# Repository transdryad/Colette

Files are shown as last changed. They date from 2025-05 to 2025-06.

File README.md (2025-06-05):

# Colette

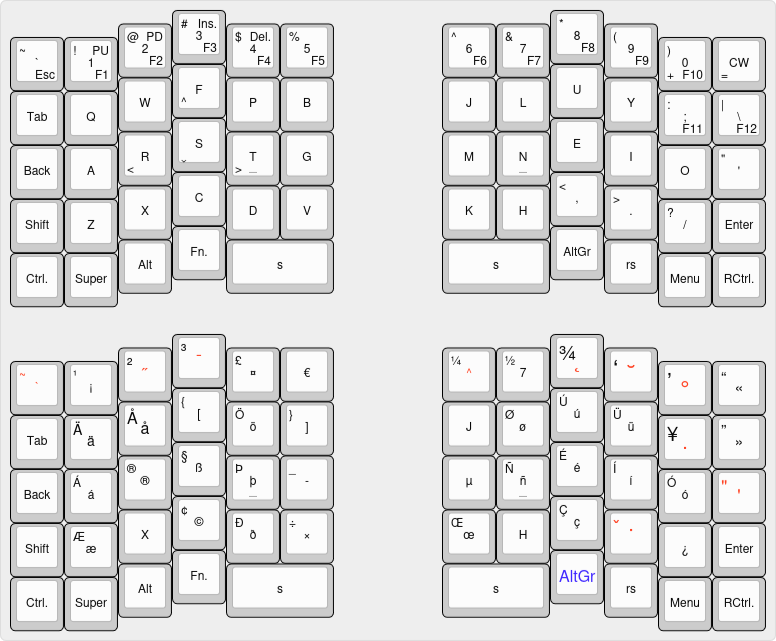
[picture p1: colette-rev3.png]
Colette

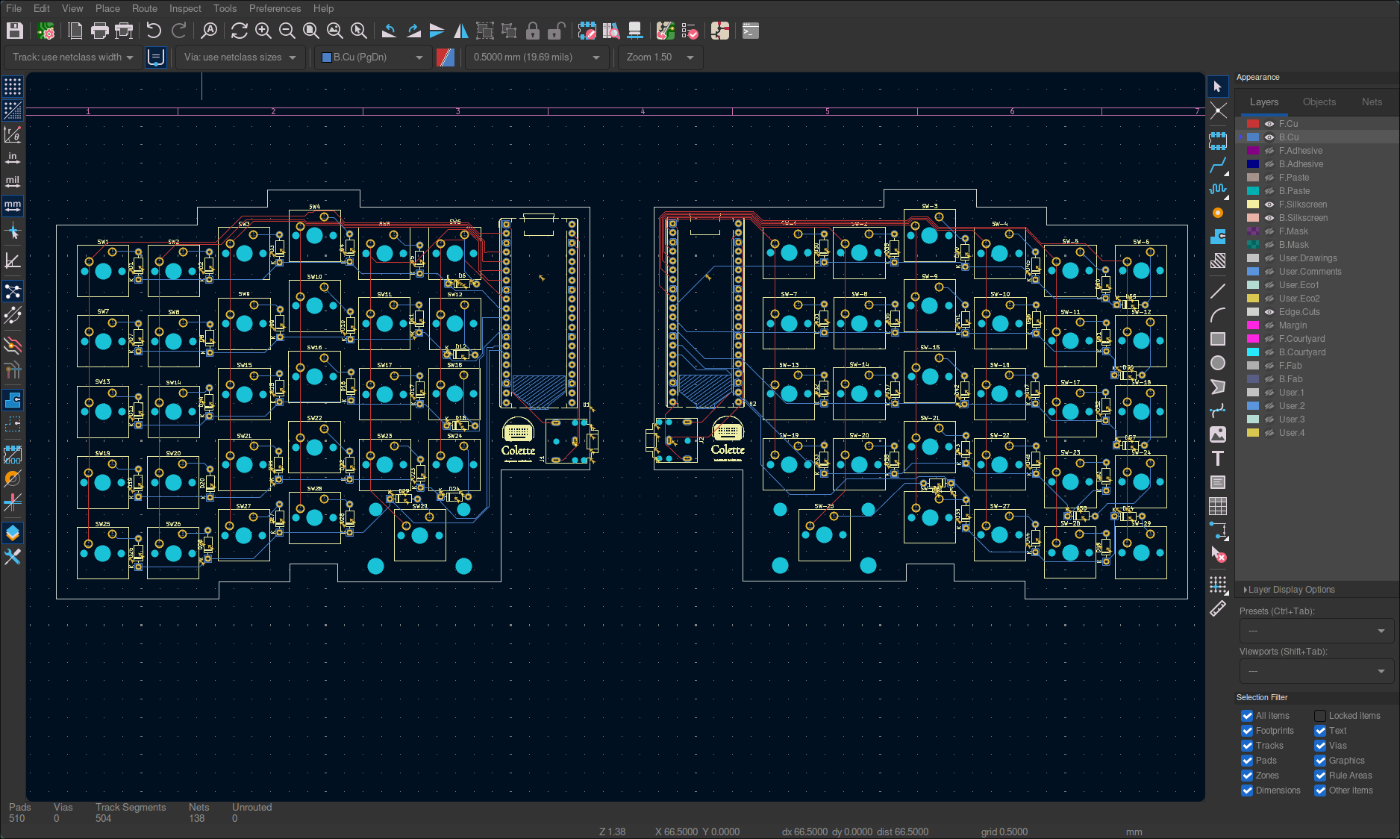
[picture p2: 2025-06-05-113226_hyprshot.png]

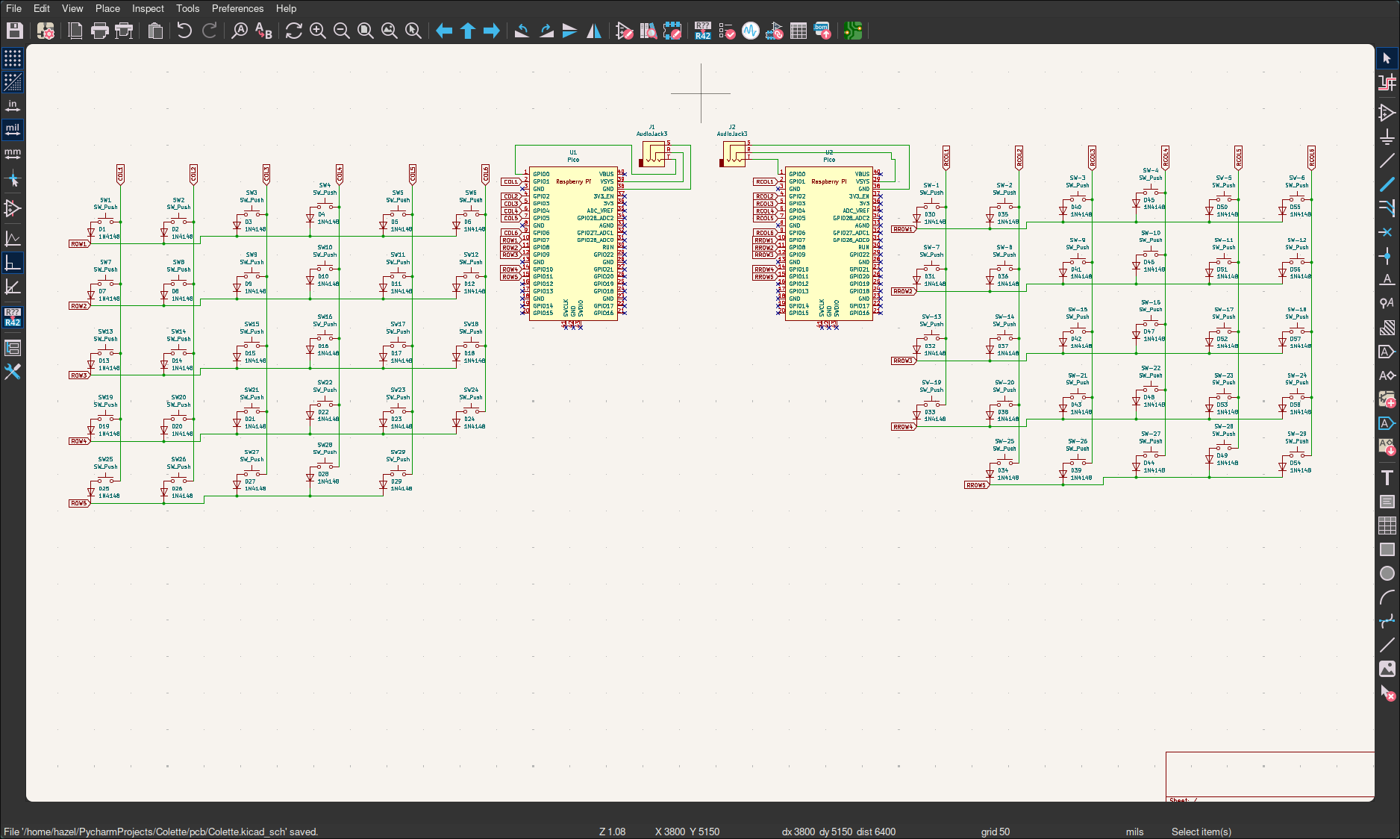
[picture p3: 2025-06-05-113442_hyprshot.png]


A keyboard designed to be ergonomic, clean, convenient, maintainable, and versatile.
It is optimized for English, but can type every character supported by the US International layout (though it's not followed or fully required for basic usage.)
By default, it uses Colemak Mod-DH with a few changes to punctuation.

I made this keyboard to get more experience building hardware and enable a more cohesive coding environment.
I also wanted it to be good at typing text as well and have support for similar languages to english like French,
Spanish, and German.

* Keyboard Maintainer: [Hazel Viswanath](https://github.com/transdryad)
* Hardware Supported: Colette PCB, RPi/Orpheus Pico v1, Cherry MX keys, standard TRS jack

# Software used:
Kicad, Pycharm, FreeCAD, QMK, and Keyboard-Layout-Editor.com

# Firmware:
To compile & flash formware, install qmk system-wide and run bf.sh.
When it's "waiting for drive," plug in while pressing the BOOTSEL button on the PICO.
WARNING: the script will delete qmk firmware monorepo tree.
Backup any changes.

# BOM

BOM also in BOM.csv

| Part | Quantity | Proposed Sourcing? |
|:---|:---|:---|
| PCBs | 2 | https://jlcpcb.com |
| KeySwitches | 58 | https://mechanicalkeyboards.com/products/cherry-mx2a-brown-55g-tactile?variant=48020838351148 |
| Keycaps | ~58 | https://www.amazon.com/YMDK-Profile-Keyset-Mechanical-Keyboard/dp/B07S18VCDN?th=1 |
| 1N4148 Diodes | 58 | https://www.digikey.com/en/products/detail/onsemi/1N4148/458603 |
| TRS Jacks | 2 | https://www.digikey.com/en/products/detail/same-sky-formerly-cui-devices/SJ1-3523N/738689 |
| TRS Cables | 1 | https://www.mycablemart.com/store/cart.php?m=product_detail&p=9040 |
| Orpheus Picos | 2 | HQ? |
| M3x16mm Screws | 8 | ? |
| M3x5mx4mm headset inserts | 8 | ? |
| Case | 4 parts  | Printing legion? |

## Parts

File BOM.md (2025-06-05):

PCBs (2): https://jlcpcb.com
Switches (58): https://mechanicalkeyboards.com/products/cherry-mx2a-brown-55g-tactile?variant=48020838351148
Keycaps (58): https://www.amazon.com/YMDK-Profile-Keyset-Mechanical-Keyboard/dp/B07S18VCDN?th=1 (picked as it contains all sizes that I need w/ exactly the right amount of 1Us.)
Diodes (58): https://www.digikey.com/en/products/detail/onsemi/1N4148/458603
TRS Jacks (2): https://www.digikey.com/en/products/detail/same-sky-formerly-cui-devices/SJ1-3523N/738689
1.5 ft. TRS Cable (1): https://www.mycablemart.com/store/cart.php?m=product_detail&p=9040
Orpheus Picos (2): Hack Club?
M3x16mm Screws (8): ?
M3x5mx4mm headset inserts (8): ?
Case(s) (4 parts): printing legion?

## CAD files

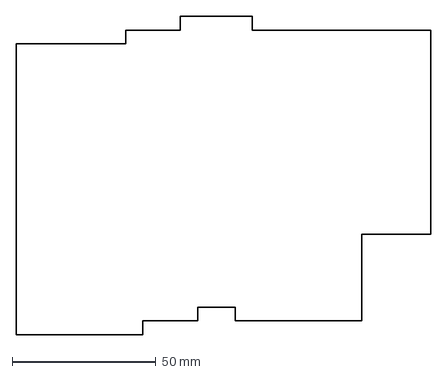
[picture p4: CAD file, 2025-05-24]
CAD/FCSrc/main-BodySketch.dxf
144.3 x 110.8 mm

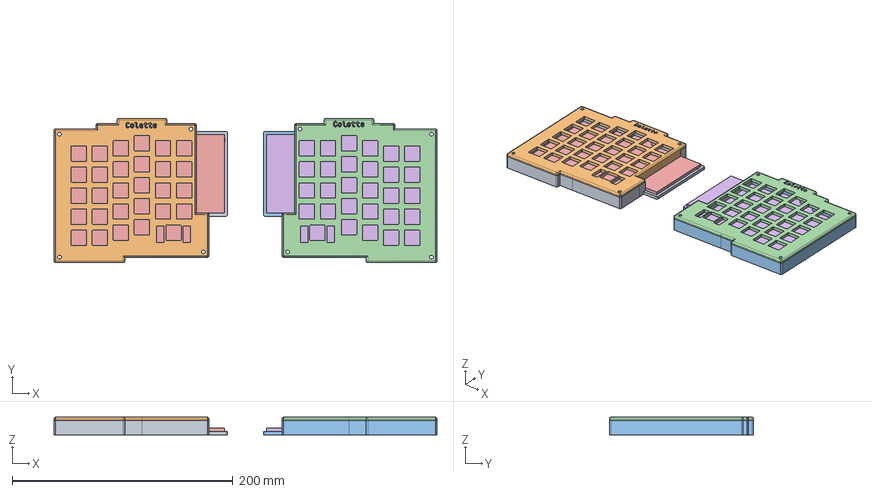
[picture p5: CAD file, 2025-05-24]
CAD/FCSrc/main.FCStd
346.9 x 130.8 x 16.0 mm
Plate

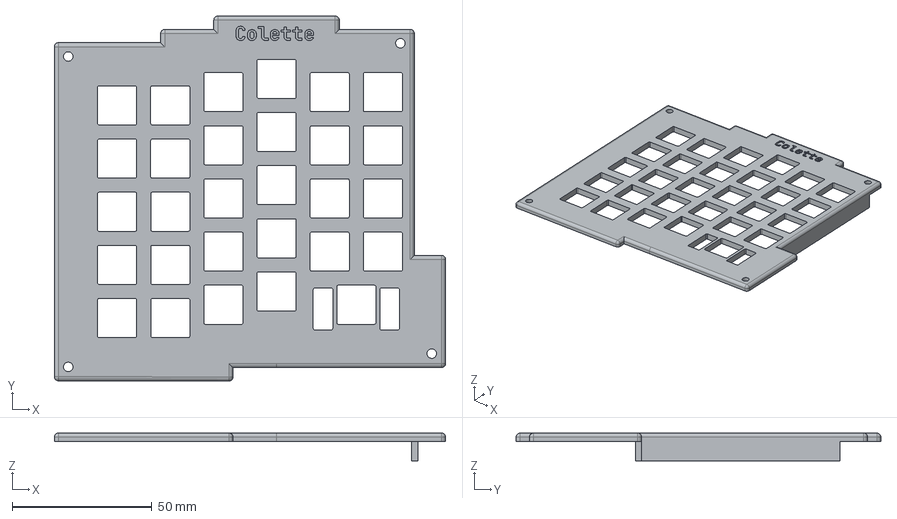
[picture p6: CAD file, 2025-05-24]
production/CAD/plate-left.step
140.3 x 130.8 x 10.0 mm

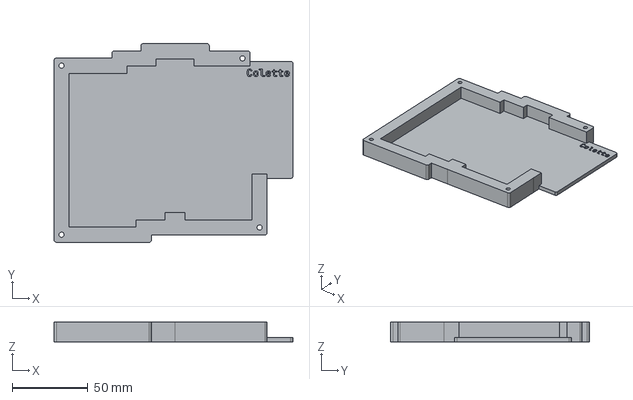
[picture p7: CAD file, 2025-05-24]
production/CAD/case-left.step
157.3 x 130.8 x 13.0 mm

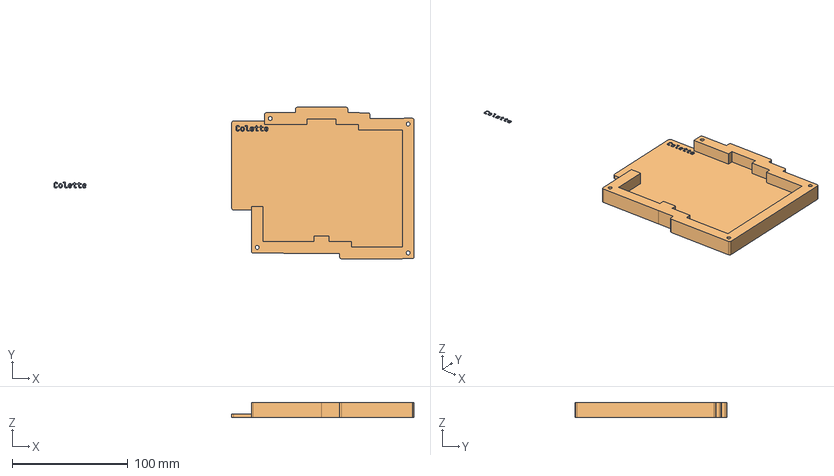
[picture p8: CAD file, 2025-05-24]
production/CAD/case-right.step
310.7 x 130.8 x 13.0 mm
ShapeString002

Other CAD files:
CAD/FCSrc/main-er.FCStd
CAD/all-with-mock-pcb.step
production/CAD/plate-right.step

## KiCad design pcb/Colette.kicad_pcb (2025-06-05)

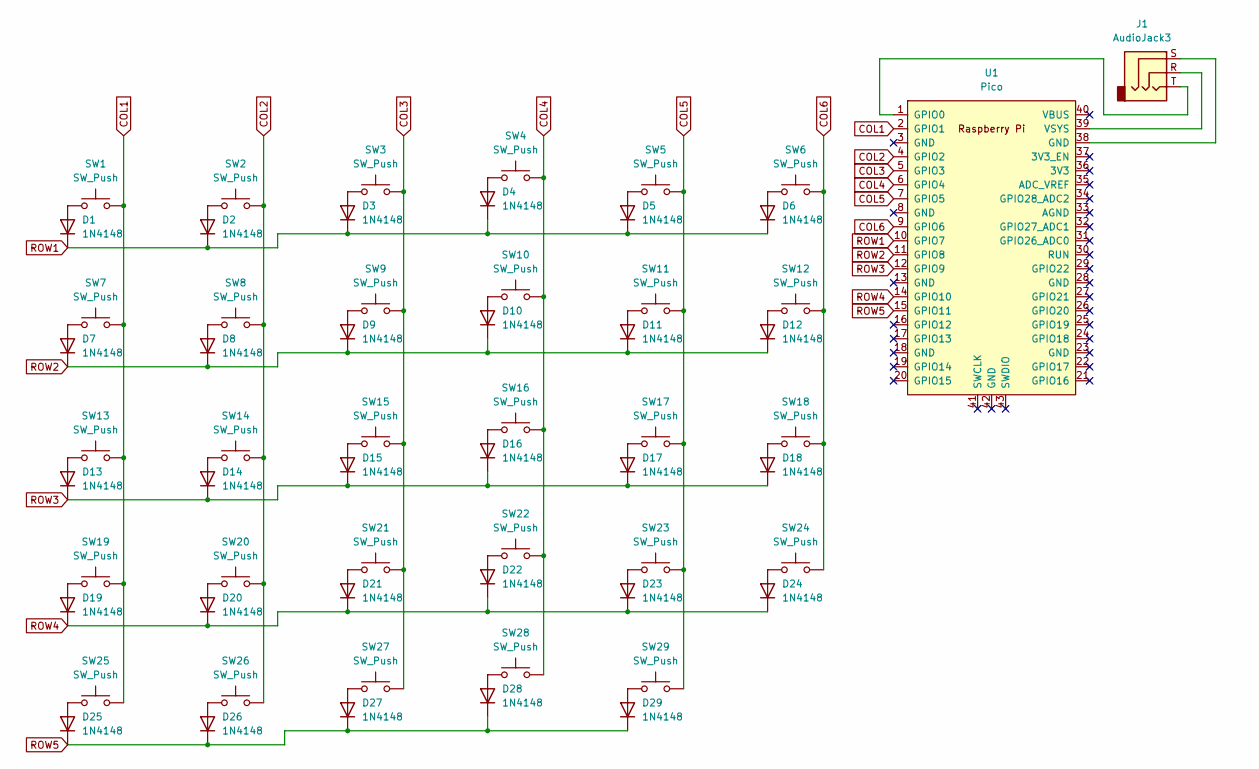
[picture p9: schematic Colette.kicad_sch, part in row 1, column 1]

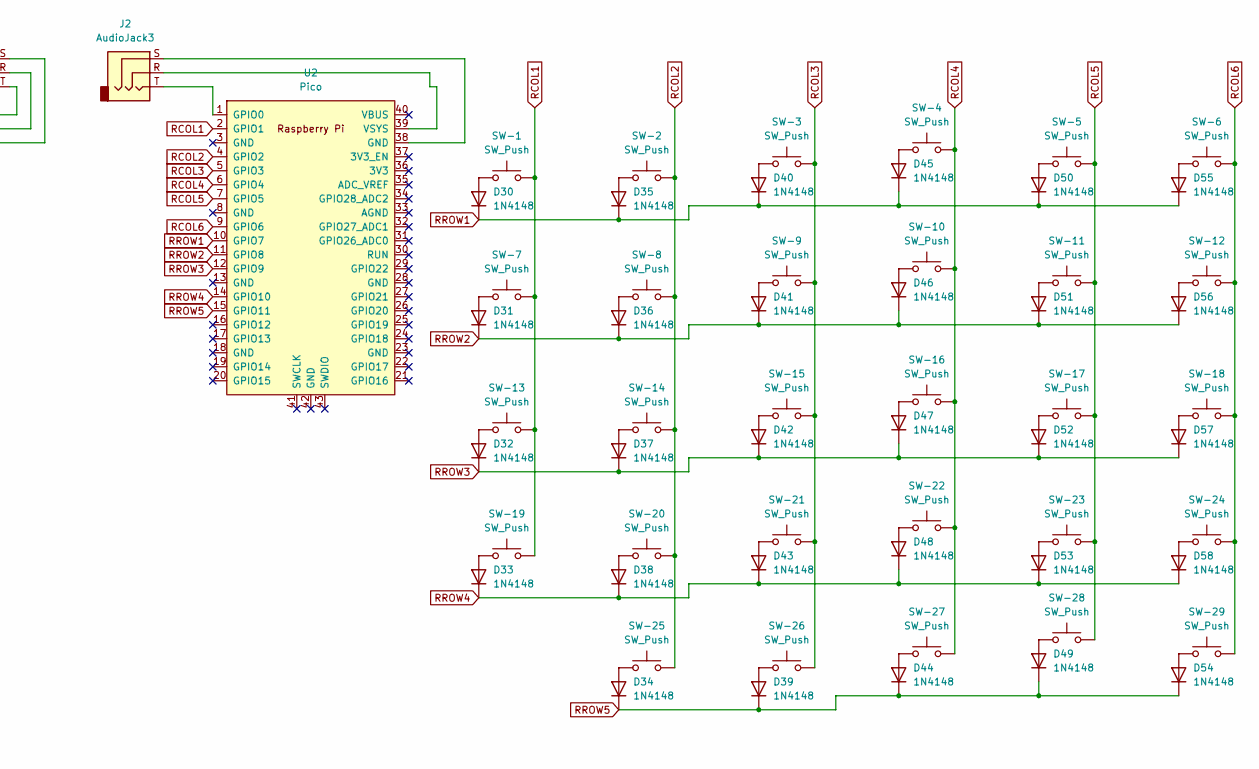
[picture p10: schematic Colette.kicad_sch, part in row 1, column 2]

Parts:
D1, D2, D3, D4, D5, D6, D7, D8, D9, D10, D11, D12, D13, D14, D15, D16, D17, D18, D19, D20, D21, D22, D23, D24, D25, D26, D27, D28, D29, D30, D31, D32, D33, D34, D35, D36, D37, D38, D39, D40, D41, D42, D43, D44, D45, D46, D47, D48, D49, D50, D51, D52, D53, D54, D55, D56, D57, D58: 1N4148; D_DO-35_SOD27_P7.62mm_Horizontal
J1, J2: AudioJack3; Jack_3.5mm_CUI_SJ1-3523N_Horizontal
SW1, SW2, SW3, SW4, SW5, SW6, SW7, SW8, SW9, SW10, SW11, SW12, SW13, SW14, SW15, SW16, SW17, SW18, SW19, SW20, SW21, SW22, SW23, SW24, SW25, SW26, SW27, SW28: SW_Push; SW_Cherry_MX_1.00u_PCB
SW29: SW_Push; SW_Cherry_MX_2.00u_PCB
SW-1, SW-2, SW-3, SW-4, SW-5, SW-6, SW-7, SW-8, SW-9, SW-10, SW-11, SW-12, SW-13, SW-14, SW-15, SW-16, SW-17, SW-18, SW-19, SW-20, SW-21, SW-22, SW-23, SW-24, SW-26, SW-27, SW-28, SW-29: SW_Push; SW_Cherry_MX_1.00u_PCB
SW-25: SW_Push; SW_Cherry_MX_2.00u_PCB
U1, U2: Pico; RaspberryPi_Pico_Common_THT

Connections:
COL1: SW1.2, SW7.2, SW13.2, SW19.2, SW25.2, U1.2 (GPIO1)
COL2: SW2.2, SW8.2, SW14.2, SW20.2, SW26.2, U1.4 (GPIO2)
COL3: SW3.2, SW9.2, SW15.2, SW21.2, SW27.2, U1.5 (GPIO3)
COL4: SW4.2, SW10.2, SW16.2, SW22.2, SW28.2, U1.6 (GPIO4)
COL5: SW5.2, SW11.2, SW17.2, SW23.2, SW29.2, U1.7 (GPIO5)
COL6: SW6.2, SW12.2, SW18.2, SW24.2, U1.9 (GPIO6)
unnamed: D1.2 (A), SW1.1
unnamed: D2.2 (A), SW2.1
unnamed: D3.2 (A), SW3.1
unnamed: D4.2 (A), SW4.1
unnamed: D5.2 (A), SW5.1
unnamed: D6.2 (A), SW6.1
unnamed: D7.2 (A), SW7.1
unnamed: D8.2 (A), SW8.1
unnamed: D9.2 (A), SW9.1
unnamed: D10.2 (A), SW10.1
unnamed: D11.2 (A), SW11.1
unnamed: D12.2 (A), SW12.1
unnamed: D13.2 (A), SW13.1
unnamed: D14.2 (A), SW14.1
unnamed: D15.2 (A), SW15.1
unnamed: D16.2 (A), SW16.1
unnamed: D17.2 (A), SW17.1
unnamed: D18.2 (A), SW18.1
unnamed: D19.2 (A), SW19.1
unnamed: D20.2 (A), SW20.1
unnamed: D21.2 (A), SW21.1
unnamed: D22.2 (A), SW22.1
unnamed: D23.2 (A), SW23.1
unnamed: D24.2 (A), SW24.1
unnamed: D25.2 (A), SW25.1
unnamed: D26.2 (A), SW26.1
unnamed: D27.2 (A), SW27.1
unnamed: D28.2 (A), SW28.1
unnamed: D29.2 (A), SW29.1
unnamed: D30.2 (A), SW-1.1
unnamed: D31.2 (A), SW-7.1
unnamed: D32.2 (A), SW-13.1
unnamed: D33.2 (A), SW-19.1
unnamed: D34.2 (A), SW-25.1
unnamed: D35.2 (A), SW-2.1
unnamed: D36.2 (A), SW-8.1
unnamed: D37.2 (A), SW-14.1
unnamed: D38.2 (A), SW-20.1
unnamed: D39.2 (A), SW-26.1
unnamed: D40.2 (A), SW-3.1
unnamed: D41.2 (A), SW-9.1
unnamed: D42.2 (A), SW-15.1
unnamed: D43.2 (A), SW-21.1
unnamed: D44.2 (A), SW-27.1
unnamed: D45.2 (A), SW-4.1
unnamed: D46.2 (A), SW-10.1
unnamed: D47.2 (A), SW-16.1
unnamed: D48.2 (A), SW-22.1
unnamed: D49.2 (A), SW-28.1
unnamed: D50.2 (A), SW-5.1
unnamed: D51.2 (A), SW-11.1
unnamed: D52.2 (A), SW-17.1
unnamed: D53.2 (A), SW-23.1
unnamed: D54.2 (A), SW-29.1
unnamed: D55.2 (A), SW-6.1
unnamed: D56.2 (A), SW-12.1
unnamed: D57.2 (A), SW-18.1
unnamed: D58.2 (A), SW-24.1
unnamed: J1.S, U1.38 (GND)
unnamed: J2.S, U2.38 (GND)
unnamed: J1.T, U1.1 (GPIO0)
unnamed: J1.R, U1.39 (VSYS)
unnamed: J2.T, U2.1 (GPIO0)
unnamed: J2.R, U2.39 (VSYS)
RCOL1: SW-1.2, SW-7.2, SW-13.2, SW-19.2, U2.2 (GPIO1)
RCOL2: SW-2.2, SW-8.2, SW-14.2, SW-20.2, SW-25.2, U2.4 (GPIO2)
RCOL3: SW-3.2, SW-9.2, SW-15.2, SW-21.2, SW-26.2, U2.5 (GPIO3)
RCOL4: SW-4.2, SW-10.2, SW-16.2, SW-22.2, SW-27.2, U2.6 (GPIO4)
RCOL5: SW-5.2, SW-11.2, SW-17.2, SW-23.2, SW-28.2, U2.7 (GPIO5)
RCOL6: SW-6.2, SW-12.2, SW-18.2, SW-24.2, SW-29.2, U2.9 (GPIO6)
ROW1: D1.1 (K), D2.1 (K), D3.1 (K), D4.1 (K), D5.1 (K), D6.1 (K), U1.10 (GPIO7)
ROW2: D7.1 (K), D8.1 (K), D9.1 (K), D10.1 (K), D11.1 (K), D12.1 (K), U1.11 (GPIO8)
ROW3: D13.1 (K), D14.1 (K), D15.1 (K), D16.1 (K), D17.1 (K), D18.1 (K), U1.12 (GPIO9)
ROW4: D19.1 (K), D20.1 (K), D21.1 (K), D22.1 (K), D23.1 (K), D24.1 (K), U1.14 (GPIO10)
ROW5: D25.1 (K), D26.1 (K), D27.1 (K), D28.1 (K), D29.1 (K), U1.15 (GPIO11)
RROW1: D30.1 (K), D35.1 (K), D40.1 (K), D45.1 (K), D50.1 (K), D55.1 (K), U2.10 (GPIO7)
RROW2: D31.1 (K), D36.1 (K), D41.1 (K), D46.1 (K), D51.1 (K), D56.1 (K), U2.11 (GPIO8)
RROW3: D32.1 (K), D37.1 (K), D42.1 (K), D47.1 (K), D52.1 (K), D57.1 (K), U2.12 (GPIO9)
RROW4: D33.1 (K), D38.1 (K), D43.1 (K), D48.1 (K), D53.1 (K), D58.1 (K), U2.14 (GPIO10)
RROW5: D34.1 (K), D39.1 (K), D44.1 (K), D49.1 (K), D54.1 (K), U2.15 (GPIO11)

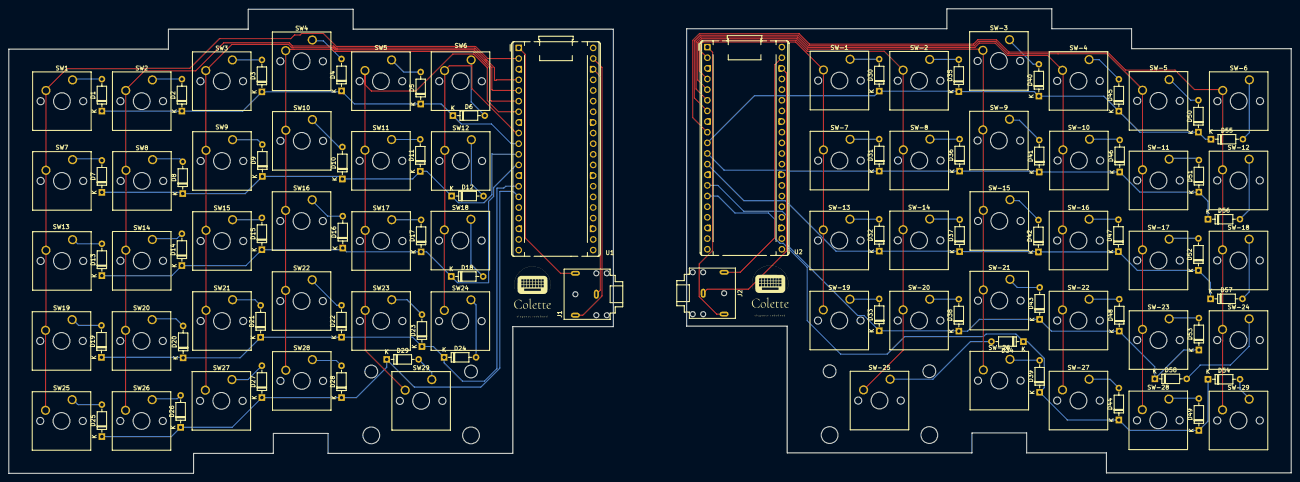
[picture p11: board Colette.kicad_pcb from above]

Board: 2 copper layers, 306.1 x 110.9 mm, 120 parts (0 on the bottom side), 86 nets.

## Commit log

2025-06-05 Pretty much there? may need to separate pcbs.
    [Colette-B_Cu.gbl, Colette-B_Mask.gbs, Colette-B_Paste.gbp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]
2025-06-05 BOM in csv.
    [BOM.csv, Colette.csv]
